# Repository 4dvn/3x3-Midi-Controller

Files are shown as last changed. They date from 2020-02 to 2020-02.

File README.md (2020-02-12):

## 3x3-Midi-Controller
Image description

I wanted to build a small midi controller. It should be cheap, 3d-printable and with usb.
## Table of Contents
* Parts
* Enclosure
* Electronics
* Drivers
* Library
* Assembly
## Parts
I bought the cheapest 100k linear potentiometers I could find (10k or 50k would be fine to, logarithmic ones would also be ok). Just search for B100K or B50K on your favourite site.

As controller, I needed a board with an Atmega32u4 chip for usb support. I got a clone of an Arduino micro pro (this is not an official arduino board, it was a Sparkfun board) You can find it if you search for "arduino micro pro usb atmega32u4 5v".
Image description 
Image description
## Enclosure
I decided to go with a 3 by 3 matrix of potentiometers and designed an enclosure in Fusion 360.

I modelled everything as one box with the hole in the top (the blue part) and added a base for the bottom to close everything up. I also moddeled a few knobs for the potentiometers. The print was pretty straight forward.
Image description
Image description
Image description
The Fusion 360 files for the parts and the stls can be downloaded here: https://github.com/4dvn/3x3-Midi-Controller/tree/master/Case
## Electronics
I put all the potentiometers in their holes. It was a pretty tight fit, some pins had to be bent. The next time I will give me a millimetre or two more.

I soldered all the right pins together and all the left pins together. One of them I soldered to ground and the other to 5V. To find out which side you want to solder to ground or 5V, you have to measure with a multimeter. Turn the potentiometer all the way low and measure the resistance between the middle pin and the outside pins. The pin which is 0 ohms you want to connect to ground, the other to 5V.
Image description
 Now connect all the middle pins of the potentiometer to a cable and the other side to the analog pins of the controller. You can find the pinout here: https://learn.sparkfun.com/tutorials/pro-micro--fio-v3-hookup-guide
Image description
Take notes which potentiometer you connect to which pin.
Image description
## Drivers
Follow these instructions and install the driver for the controller and prepare the arduino IDE. https://learn.sparkfun.com/tutorials/pro-micro--fio-v3-hookup-guide/installing-windows
When there are problems with the programming, here is a trouble shooting guide https://learn.sparkfun.com/tutorials/pro-micro--fio-v3-hookup-guide#troubleshooting-and-faq I for example had problems to get the controller programmed. I had to double reset it and chose the com port every time again.
## Library
```
https://github.com/tttapa/Control-Surface/releases
https://github.com/arduino-libraries/MIDIUSB/releases
```

## Assembly
There is nothing more to do then to glue the controller in place, close the bottom up and put the caps on the knobs.
Image description

## Contributors

Thanks to the following people who have contributed to this project:

* https://github.com/4dvn
* https://useless.blue/authors/dergrossedaniel/
* https://github.com/DerGrosseDaniel

## Contact

If you want to contact me you can reach me at <vuha.hau@hyper.vn>.

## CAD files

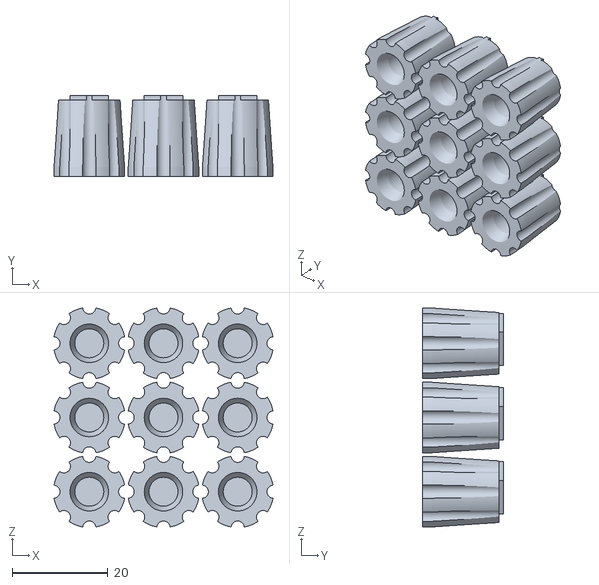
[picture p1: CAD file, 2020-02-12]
Case/PotiKnobV3.stl
45.7 x 17.0 x 45.7

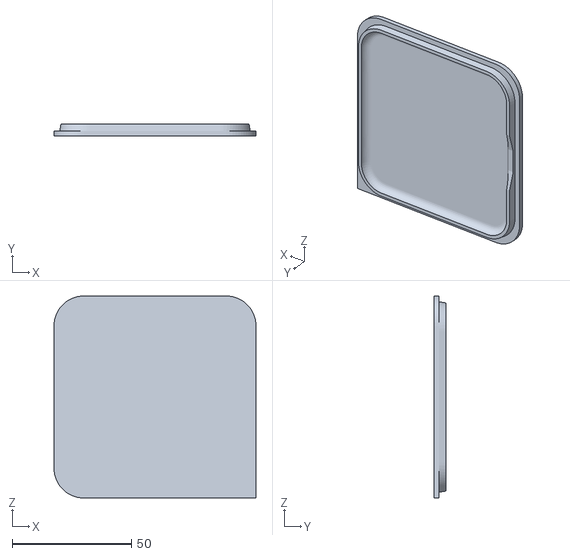
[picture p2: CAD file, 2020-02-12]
Case/MidiControllerBase.stl
84.8 x 5.00 x 84.8

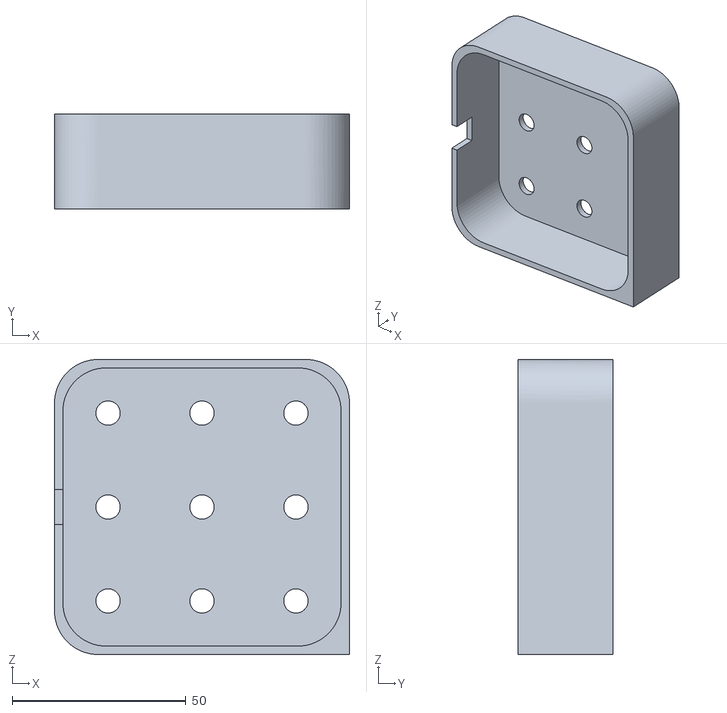
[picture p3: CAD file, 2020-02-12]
Case/MidiControllerBox.stl
84.8 x 27.4 x 84.8

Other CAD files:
Case/MidiControllerV3.f3d
Case/PotiKnobV3.f3d

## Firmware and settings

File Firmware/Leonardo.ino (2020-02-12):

#include <Control_Surface.h>

USBMIDI_Interface midi;
// Fours potentiometer to analog pinout

CCPotentiometer potentiometer1(A0, {MIDI_CC::Channel_Volume, CHANNEL_1});

CCPotentiometer potentiometer2(A1, {MIDI_CC::Channel_Volume, CHANNEL_2});

CCPotentiometer potentiometer3(A2, {MIDI_CC::Channel_Volume, CHANNEL_3});

CCPotentiometer potentiometer4(A3, {MIDI_CC::Channel_Volume, CHANNEL_4});

CCPotentiometer potentiometer5(A6, {MIDI_CC::Channel_Volume, CHANNEL_5});

CCPotentiometer potentiometer6(A7, {MIDI_CC::Channel_Volume, CHANNEL_6});

CCPotentiometer potentiometer7(A8, {MIDI_CC::Channel_Volume, CHANNEL_7});

CCPotentiometer potentiometer8(A9, {MIDI_CC::Channel_Volume, CHANNEL_8});

CCPotentiometer potentiometer9(A10, {MIDI_CC::Channel_Volume, CHANNEL_9});

void setup() {
  Control_Surface.begin();
}

void loop() {
  Control_Surface.loop();
}
